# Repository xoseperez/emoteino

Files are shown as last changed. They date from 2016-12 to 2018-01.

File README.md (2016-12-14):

# Moteino Energy Monitor

A simple energy monitor shield for Moteino and the needed firmware to make it work with different configurations.

## Features

* LiPo battery connector with battery monitor at A7 (470k resistors for low power)
* Simple biased reading (low consumption voltage divider) with optional burden resistor
* 3.5mm jack input compatible with most CT out there
* Stackable up to 3 shields to read 3 different lines.
* Jumper pads to select input pin (A1, A2 or A3)

Check my **[Moteino Energy Monitor Shield][1]** post for further information about this project.

## Hardware

The hardware is shield for **Moteino** with a **battery monitor circuitry** and a **3.5mm plug** for commonly available current transformers (a.k.a. non-invasive current sensors). There is a footprint for an optional burden resistor (SMD0805) and a bias voltage divider using 2 470K resistors for low power consumption.

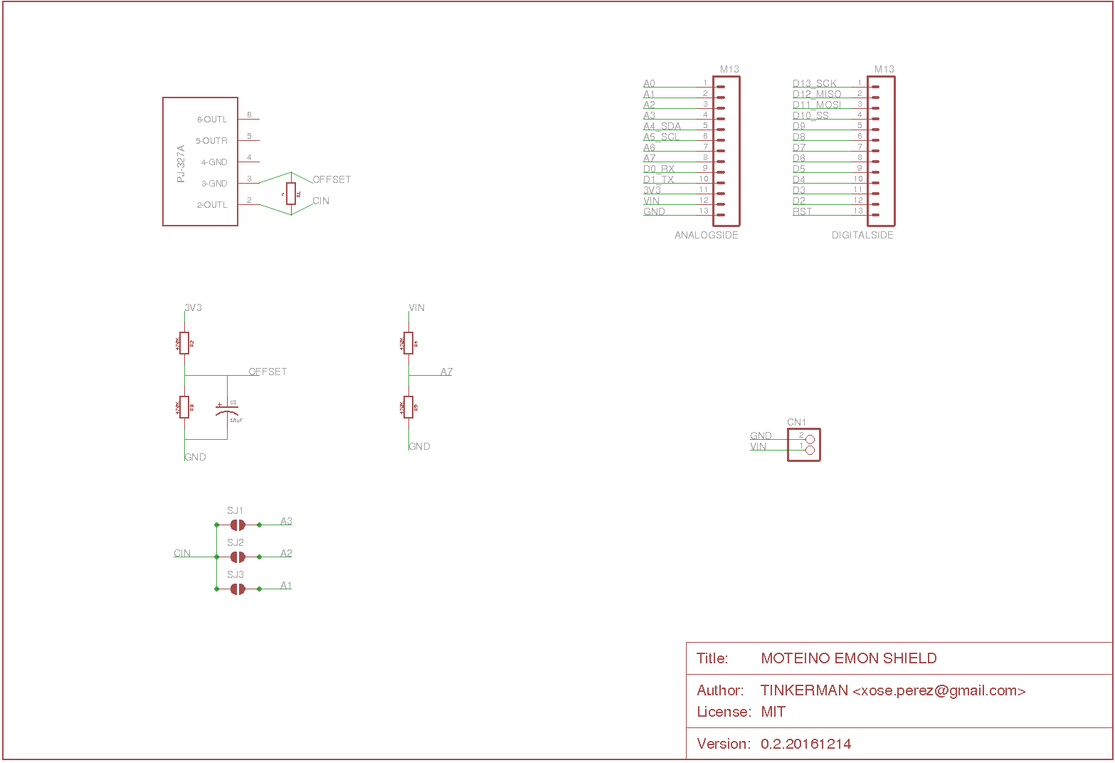
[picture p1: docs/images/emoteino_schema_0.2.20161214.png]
Energy Monitor Shield Schematic


The battery monitoring is based on a voltage divider with (again) two 470k resistors. The downstream resistor is tied to GND and the mid point to A7.

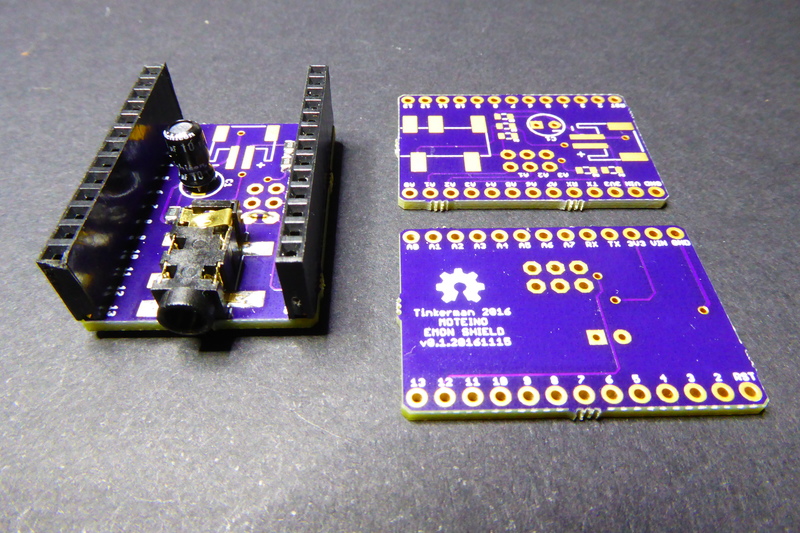
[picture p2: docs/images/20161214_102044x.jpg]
Energy Monitor Shield


## Firmware for Moteino + RFM69

### Dependencies

The code is very straight forward and there are comments where I thought it was important. It uses the following libraries:

* **[RFM69_ATC][3]** by Felix Rusu and Thomas Studwell
* **[Low-Power][4]** by RocketScream

These libraries will be automatically installed if you use [PlatformIO][2].

It also relies on my **RFM69Manager library** to wrap RFM69_ATC. This library manages radio setup and also message sending protocol. Messages from this node have the following format: ```<key>:<value>:<packetID>```. Packet ID is then used in the gateway to detect duplicates or missing packets from a node. If you don't want to send the packetID change the SEND_PACKET_ID value in RFM69Manager.h to 0.

### Configuration

Rename or copy the settings.h.sample file to settings.h and change its values to fit your needs. Check the descriptions for each value.

### Flashing

The project is ready to be build using **[PlatformIO][2]**.
Please refer to their web page for instructions on how to install the builder. Once installed connect the Moteino to your favourite FTDI-like programmer and:

```bash
> platformio run --target upload
```

[1]: http://tinkerman.cat/moteino-energy-monitor-shield/
[2]: http://www.platformio.org
[3]: https://github.com/LowPowerLab/RFM69
[4]: https://github.com/rocketscream/Low-Power/

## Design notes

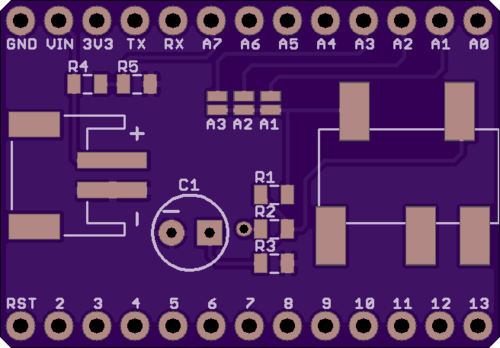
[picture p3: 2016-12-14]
docs/images/emoteino_board_0.2.20161214_top.png

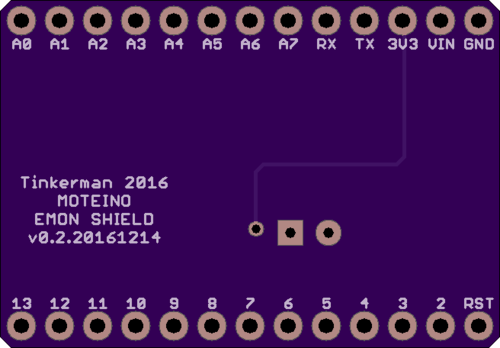
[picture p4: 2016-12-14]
docs/images/emoteino_board_0.2.20161214_bottom.png

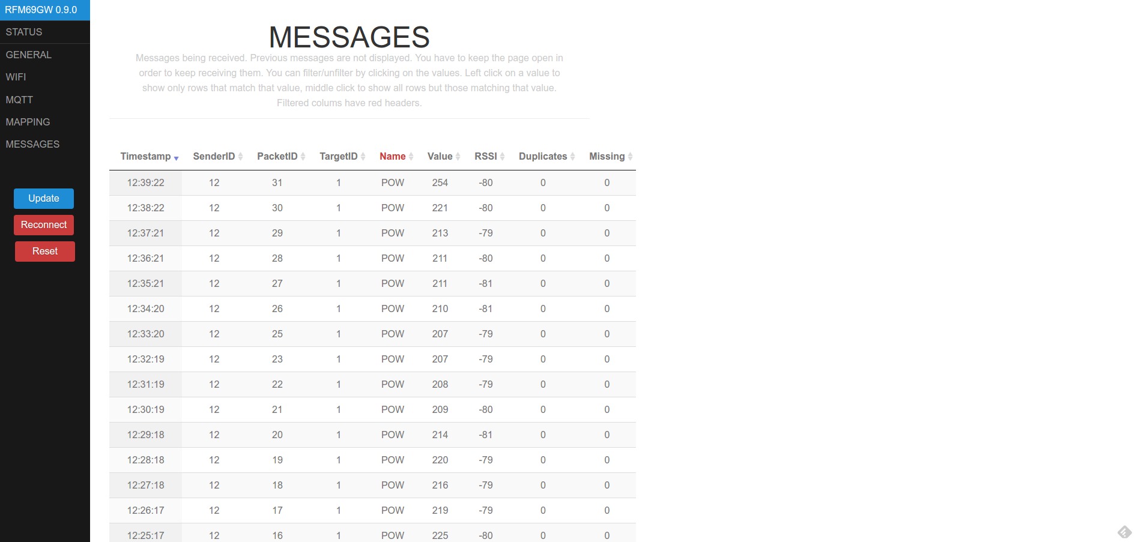
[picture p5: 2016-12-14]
docs/images/rfm69gw_screenshot.jpeg

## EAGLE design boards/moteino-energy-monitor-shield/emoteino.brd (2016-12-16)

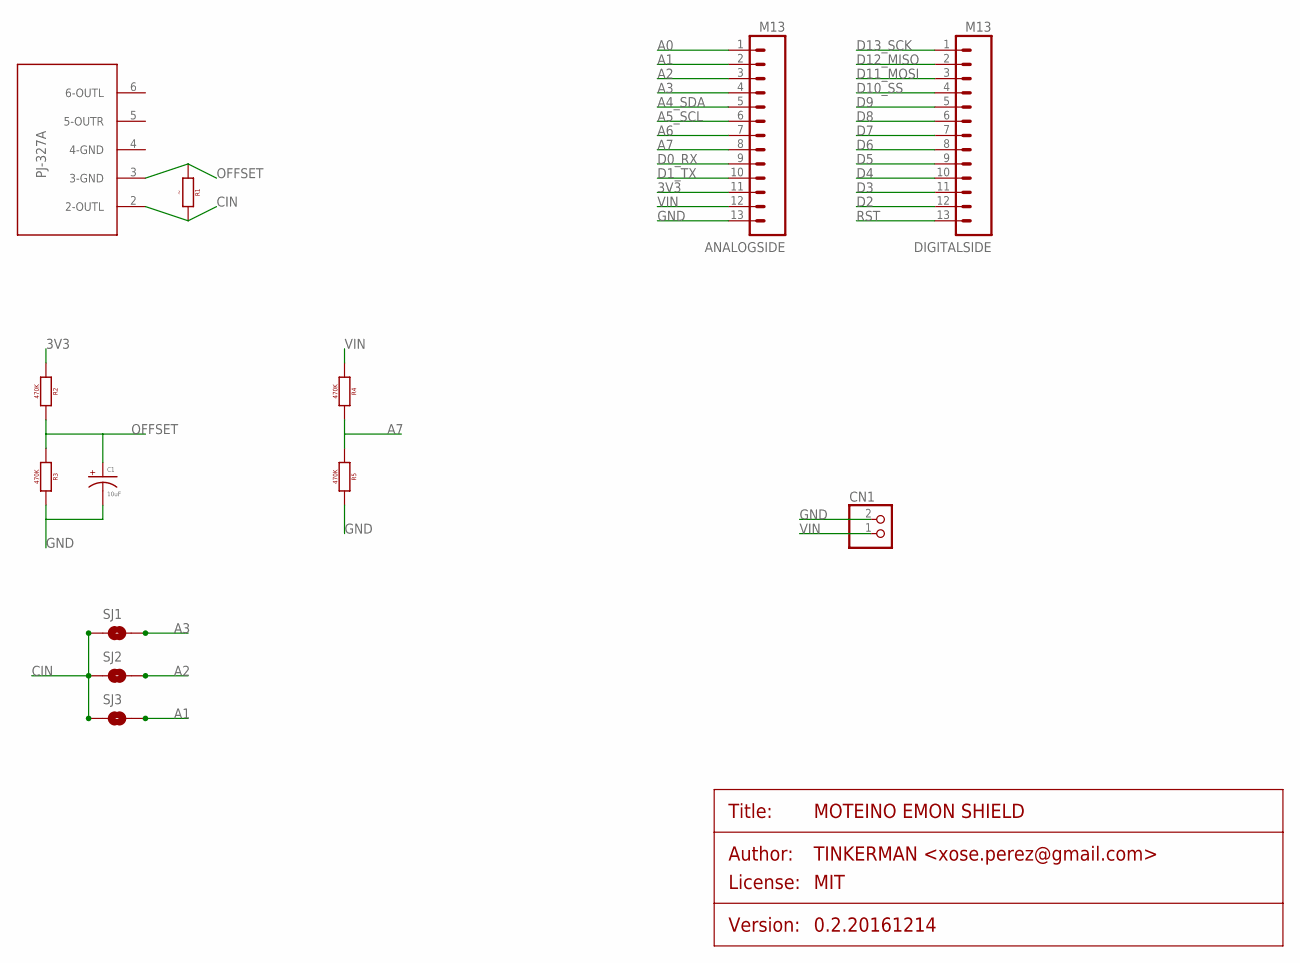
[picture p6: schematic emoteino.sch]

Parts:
ANALOGSIDE: M13; 1X13_NO_SILK
C1: 10uF; CPOL-RADIAL-10UF-25V
CN1: JST_2PIN-SMT-RA; JST-PH-2-SMT-RA
CURR1: PJ-327A
DIGITALSIDE: M13; 1X13_NO_SILK
R1: 0805
R2, R3, R4, R5: 470K; 0805
SJ1, SJ2, SJ3: SOLDERJUMPERNO; SJ_2S-NO

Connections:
3V3: ANALOGSIDE.11, R2.1
A0: ANALOGSIDE.1
A1: ANALOGSIDE.2, SJ3.2
A2: ANALOGSIDE.3, SJ2.2
A3: ANALOGSIDE.4, SJ1.2
A4_SDA: ANALOGSIDE.5
A5_SCL: ANALOGSIDE.6
A6: ANALOGSIDE.7
A7: ANALOGSIDE.8, R4.2, R5.1
CIN: CURR1.2 (2-OUTL), R1.2, SJ1.1, SJ2.1, SJ3.1
D0_RX: ANALOGSIDE.9
D1_TX: ANALOGSIDE.10
D2: DIGITALSIDE.12
D3: DIGITALSIDE.11
D4: DIGITALSIDE.10
D5: DIGITALSIDE.9
D6: DIGITALSIDE.8
D7: DIGITALSIDE.7
D8: DIGITALSIDE.6
D9: DIGITALSIDE.5
D10_SS: DIGITALSIDE.4
D11_MOSI: DIGITALSIDE.3
D12_MISO: DIGITALSIDE.2
D13_SCK: DIGITALSIDE.1
GND: ANALOGSIDE.13, C1.2 (-), CN1.2 (1), R3.2, R5.2
OFFSET: C1.1 (+), CURR1.3 (3-GND), R1.1, R2.2, R3.1
RST: DIGITALSIDE.13
VIN: ANALOGSIDE.12, CN1.1 (2), R4.1

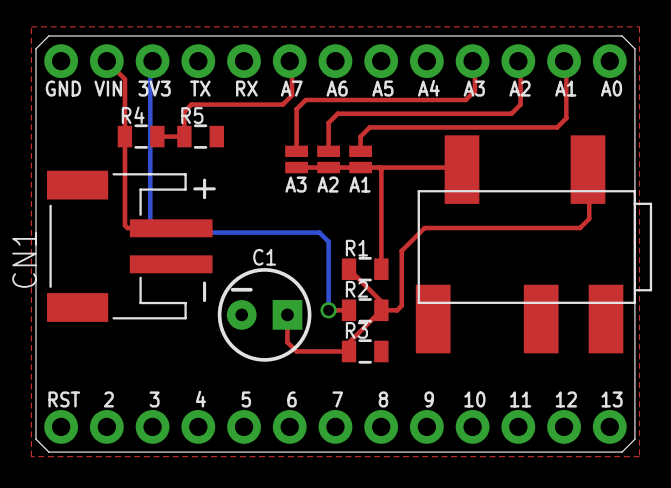
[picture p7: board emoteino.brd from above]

Board: 2 copper layers, 33.3 x 23.1 mm, 13 parts (0 on the bottom side), 9 nets.

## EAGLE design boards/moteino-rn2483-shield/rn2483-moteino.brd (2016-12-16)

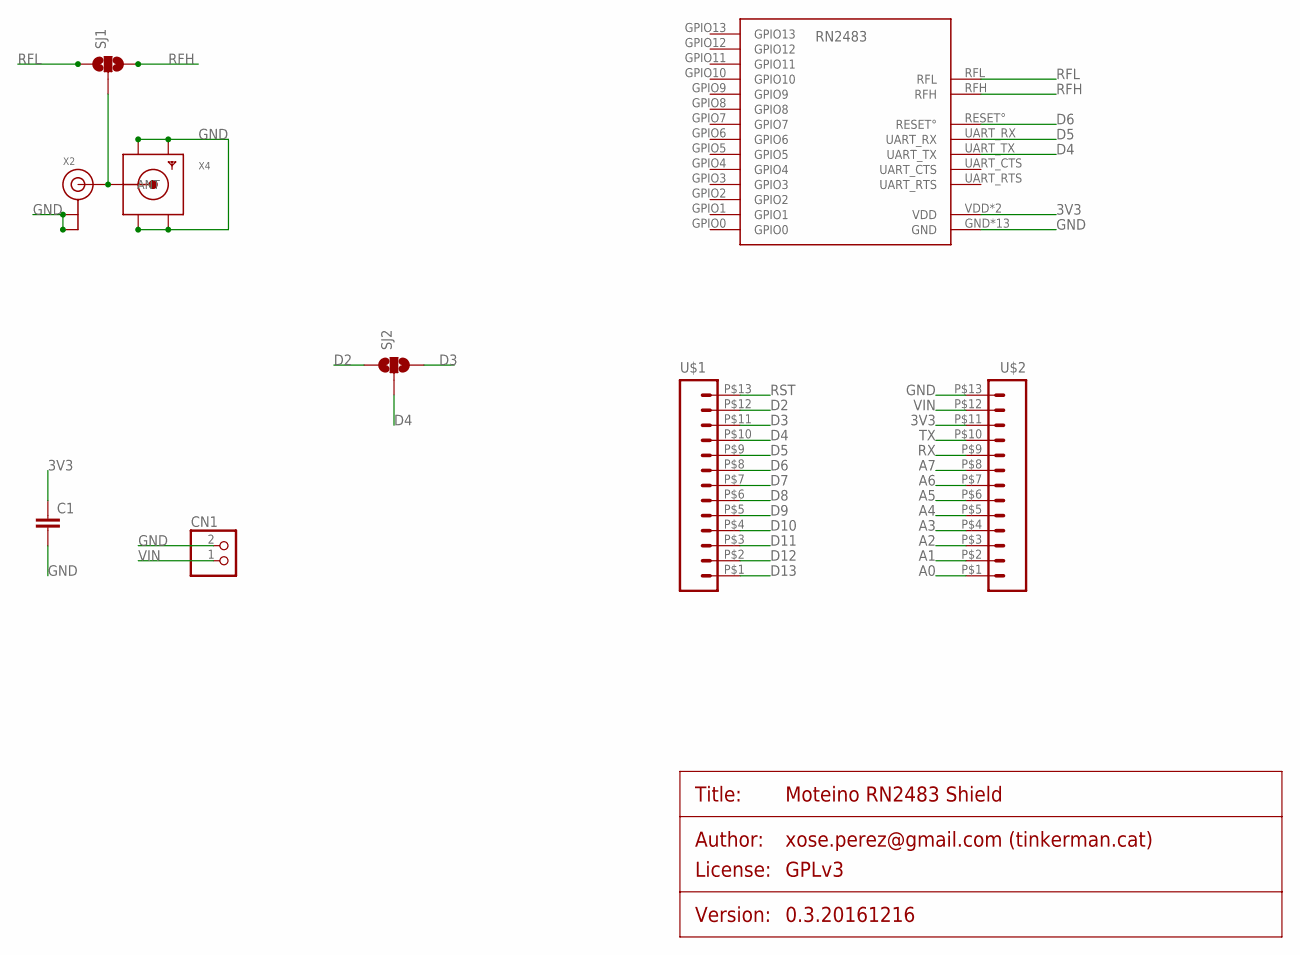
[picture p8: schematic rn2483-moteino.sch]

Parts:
C1: C-EU0805; 0805
CN1: JST_2PIN-SMT-RA; JST-PH-2-SMT-RA
RN2483: RN2483ALLPINS; RN2483
SJ1, SJ2: SOLDERJUMPER_2WAYS; SJ_3
U$1, U$2: M13M13_1X13_SMD; 1X13_SMD
X2: ANTENNA_U.FL; U.FL
X4: SMACONNECTOR_EDGE; SMA_EDGELAUNCH

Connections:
3V3: C1.1, RN2483.VDD, RN2483.VDD2 (VDD), U$2.P$11 (11)
A0: U$2.P$1 (1)
A1: U$2.P$2 (2)
A2: U$2.P$3 (3)
A3: U$2.P$4 (4)
A4: U$2.P$5 (5)
A5: U$2.P$6 (6)
A6: U$2.P$7 (7)
A7: U$2.P$8 (8)
D2: SJ2.1, U$1.P$12 (12)
D3: SJ2.3, U$1.P$11 (11)
D4: RN2483.UART_TX, SJ2.2, U$1.P$10 (10)
D5: RN2483.UART_RX, U$1.P$9 (9)
D6: RN2483.RESET°, U$1.P$8 (8)
D7: U$1.P$7 (7)
D8: U$1.P$6 (6)
D9: U$1.P$5 (5)
D10: U$1.P$4 (4)
D11: U$1.P$3 (3)
D12: U$1.P$2 (2)
D13: U$1.P$1 (1)
GND: C1.2, CN1.2 (1), RN2483.GND, RN2483.GND1 (GND), RN2483.GND2 (GND), RN2483.GND3 (GND), RN2483.GND4 (GND), RN2483.GND5 (GND), RN2483.GND6 (GND), RN2483.GND7 (GND), RN2483.GND8 (GND), RN2483.GND9 (GND), RN2483.GND10 (GND), RN2483.GND11 (GND), RN2483.GND12 (GND), U$2.P$13 (13), X2.1 (GND), X2.2 (GND), X4.GND@1 (GND4), X4.GND@2 (GND3), X4.GND@3 (GND2), X4.GND@4 (GND1)
unnamed: SJ1.2, X2.3 (SIGNAL), X4.P (ANT)
RFH: RN2483.RFH, SJ1.3
RFL: RN2483.RFL, SJ1.1
RST: U$1.P$13 (13)
RX: U$2.P$9 (9)
TX: U$2.P$10 (10)
VIN: CN1.1 (2), U$2.P$12 (12)

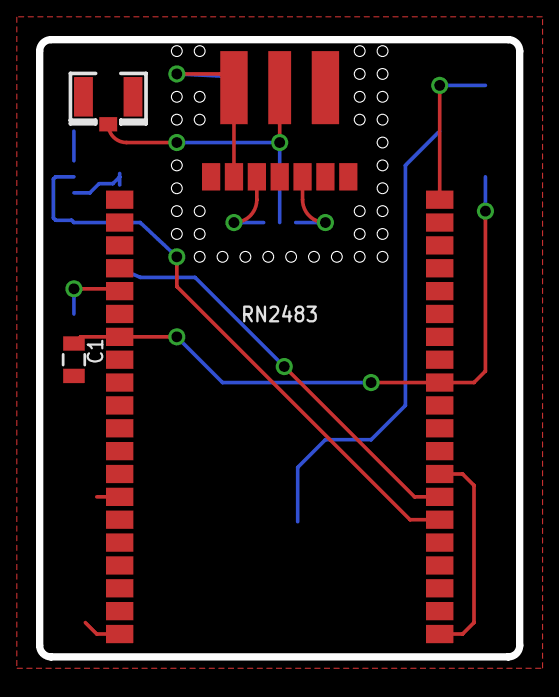
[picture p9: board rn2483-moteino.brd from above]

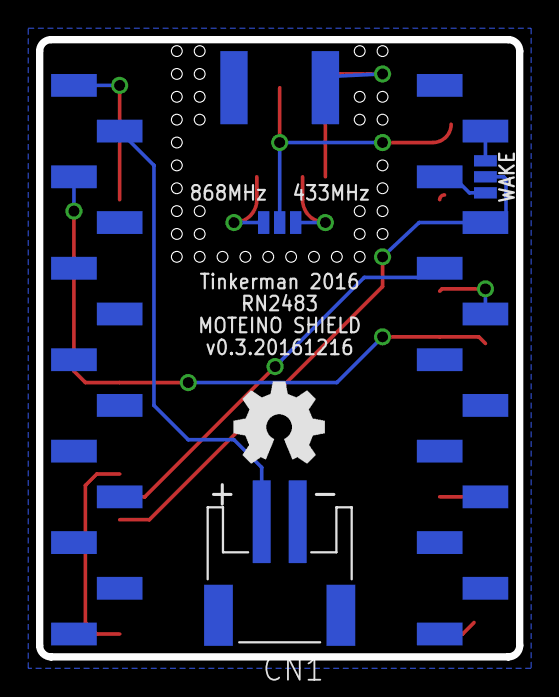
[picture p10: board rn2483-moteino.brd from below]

Board: 2 copper layers, 26.7 x 34.3 mm, 9 parts (5 on the bottom side), 11 nets.

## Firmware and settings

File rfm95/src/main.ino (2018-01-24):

/*

RFM95 TTN EU NODE

Copyright (C) 2016-2018
Xose Pérez <xose dot perez at gmail dot com>
for The Things Network Catalunya Wiki (http://thethingsnetwork.cat)
Based on LMIC library example

This sketch sends an incrementing number every minute

This sketch requires LMIC library by Matthijs Kooijman
https://github.com/matthijskooijman/arduino-lmic

// -----------------------------------------------------------------------------
// Moteino LoRa
// https://lowpowerlab.com/shop/product/99
// -----------------------------------------------------------------------------

You will have to wire the folowing extra pins from the RFM95 module to Moteino ports:

  RFM95     Moteino
  --------  --------
  RESET     D4
  DIO1      D5
  DIO2      D6

RFM95 module pinout (top view, with the chip facing you) and the corresponding
Moteino PIN connected (wire the ones marked with an asterisk *)
        |-------------|
    GND | GND    DIO2 | D6*
    D12 | MISO   DIO1 | D5*
    D11 | MOSI   DIO0 | D2
    D13 | SCK     3V3 | 3V3
    D10 | NSS    DIO4 |
    *D4 | RESET  DIO3 |
        | DIO5    GND | GND
    GND | GND     ANT |
        |-------------|

// -----------------------------------------------------------------------------
// CH2i Wemos LoRa Shield
// https://github.com/hallard/WeMos-Lora
// -----------------------------------------------------------------------------

Default connections apply.

// -----------------------------------------------------------------------------
// Heltec WIFI LoRa 32
// https://robotzero.one/heltec-wifi-lora-32/
// -----------------------------------------------------------------------------

GPIO5  -- SX1278's SCK
GPIO19 -- SX1278's MISO
GPIO27 -- SX1278's MOSI
GPIO18 -- SX1278's CS
GPIO14 -- SX1278's RESET
GPIO26 -- SX1278's IRQ(Interrupt Request)

RFM95 module pinout (top view, with the chip facing you) and the corresponding
ESP32 PIN connected:

        |-------------|
    GND | GND    DIO2 | 32
     19 | MISO   DIO1 | 33
     27 | MOSI   DIO0 | 26
      5 | SCK     3V3 | 3V
     18 | NSS    DIO4 |
     14 | RESET  DIO3 |
        | DIO5    GND | GND
    GND | GND     ANT |
        |-------------|

// -----------------------------------------------------------------------------

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
*/

#include <Arduino.h>
#include <lmic.h>
#include <hal/hal.h>
#include <SPI.h>

#ifndef CFG_eu868
    #error "This script is meant to connect to TTN EU network at 868MHz"
#endif

// -----------------------------------------------------------------------------
// Configuration
// -----------------------------------------------------------------------------

#define SERIAL_BAUD         115200      // Serial debug baud rate
#define TX_INTERVAL         60          // Send message every these many seconds

// Copy and rename credentials.sample.h to credentials.h
// and configure it with your node settings
#include "credentials.h"

// Define device type
// Only one of these must be defined at the same time
//#define MOTEINO_LORA
//#define CH2I_WEMOS_LORA_SHIELD
//#define HELTEC_WIFI_LORA_32

// -----------------------------------------------------------------------------
// GPIO mapping
// -----------------------------------------------------------------------------

#ifdef MOTEINO_LORA
    #define NSS_GPIO        10
    #define RESET_GPIO      4
    #define DIO0_GPIO       2
    #define DIO1_GPIO       5
    #define DIO2_GPIO       6
#endif

#ifdef CH2I_WEMOS_LORA_SHIELD
    #define NSS_GPIO        16
    #define RESET_GPIO      LMIC_UNUSED_PIN
    #define DIO0_GPIO       15
    #define DIO1_GPIO       15
    #define DIO2_GPIO       15
#endif

#ifdef HELTEC_WIFI_LORA_32
    #define SCK_GPIO        5
    #define MISO_GPIO       19
    #define MOSI_GPIO       27
    #define NSS_GPIO        18
    #define RESET_GPIO      14
    #define DIO0_GPIO       26
    #define DIO1_GPIO       33
    #define DIO2_GPIO       32
#endif

#ifndef NSS_GPIO
    #error "GPIO are not mapped!!"
#endif

// -----------------------------------------------------------------------------
// Globals
// -----------------------------------------------------------------------------

// LMIC GPIO configuration
const lmic_pinmap lmic_pins = {
    .nss = NSS_GPIO,
    .rxtx = LMIC_UNUSED_PIN,
    .rst = RESET_GPIO,
    .dio = {DIO0_GPIO, DIO1_GPIO, DIO2_GPIO},
};

#if !defined(USE_ABP) && !defined(USE_OTAA)
    #error "Define either USE_ABP or USE_OTAA in credentials.h"
#endif

#ifdef USE_ABP
// These callbacks are only used in over-the-air activation, so they are
// left empty here (we cannot leave them out completely unless
// DISABLE_JOIN is set in config.h, otherwise the linker will complain).
void os_getArtEui (u1_t* buf) { }
void os_getDevEui (u1_t* buf) { }
void os_getDevKey (u1_t* buf) { }
#endif

#ifdef USE_OTAA
void os_getArtEui (u1_t* buf) { memcpy_P(buf, APPEUI, 8); }
void os_getDevEui (u1_t* buf) { memcpy_P(buf, DEVEUI, 8); }
void os_getDevKey (u1_t* buf) { memcpy_P(buf, APPKEY, 16); }
#endif

// Job
static osjob_t sendjob;

// Value
unsigned long autoincrement = 0;

// -----------------------------------------------------------------------------
// LMIC
// -----------------------------------------------------------------------------

void ttnSend(osjob_t* j){

    // Check if there is not a current TX/RX job running
    if (LMIC.opmode & OP_TXRXPEND) {
        Serial.println(F("[RFM95] Pending message"));
        return;
    }

    // Prepare buffer
    unsigned char data[4];
    data[0] = (autoincrement >> 24) & 0xFF;
    data[1] = (autoincrement >> 16) & 0xFF;
    data[2] = (autoincrement >>  8) & 0xFF;
    data[3] = (autoincrement >>  0) & 0xFF;

    // Prepare upstream data transmission at the next possible time.
    // Parameters are port, data, length, confirmed
    LMIC_setTxData2(1, data, 4, 0);

    Serial.println(F("[RFM95] Packet queued"));

    // Next TX is scheduled after TX_COMPLETE event.
    autoincrement++;

}

// LMIC library will call this method when an event is fired
void onEvent(ev_t ev) {

    Serial.print(os_getTime());
    Serial.print(": ");

    switch(ev) {
        case EV_SCAN_TIMEOUT:
            Serial.println(F("[RFM95] EV_SCAN_TIMEOUT"));
            break;
        case EV_BEACON_FOUND:
            Serial.println(F("[RFM95] EV_BEACON_FOUND"));
            break;
        case EV_BEACON_MISSED:
            Serial.println(F("[RFM95] EV_BEACON_MISSED"));
            break;
        case EV_BEACON_TRACKED:
            Serial.println(F("[RFM95] EV_BEACON_TRACKED"));
            break;
        case EV_JOINING:
            Serial.println(F("[RFM95] EV_JOINING"));
            break;
        case EV_JOINED:
            Serial.println(F("[RFM95] EV_JOINED"));
            break;
        case EV_RFU1:
            Serial.println(F("[RFM95] EV_RFU1"));
            break;
        case EV_JOIN_FAILED:
            Serial.println(F("[RFM95] EV_JOIN_FAILED"));
            break;
        case EV_REJOIN_FAILED:
            Serial.println(F("[RFM95] EV_REJOIN_FAILED"));
            break;
        case EV_TXCOMPLETE:

            Serial.println(F("[RFM95] EV_TXCOMPLETE (includes waiting for RX windows)"));

            if (LMIC.txrxFlags & TXRX_ACK) {
                Serial.println(F("[RFM95] ACK received"));
            }

            if (LMIC.dataLen) {
                Serial.print(F("[RFM95] Received "));
                Serial.print(LMIC.dataLen);
                Serial.println(F(" bytes of payload"));
            }

            // Schedule next transmission
            os_setTimedCallback(&sendjob, os_getTime() + sec2osticks(TX_INTERVAL), ttnSend);
            break;

        case EV_LOST_TSYNC:
            Serial.println(F("[RFM95] EV_LOST_TSYNC"));
            break;
        case EV_RESET:
            Serial.println(F("[RFM95] EV_RESET"));
            break;
        case EV_RXCOMPLETE:
            // data received in ping slot
            Serial.println(F("[RFM95] EV_RXCOMPLETE"));
            break;
        case EV_LINK_DEAD:
            Serial.println(F("[RFM95] EV_LINK_DEAD"));
            break;
        case EV_LINK_ALIVE:
            Serial.println(F("[RFM95] EV_LINK_ALIVE"));
            break;
        default:
            Serial.println(F("[RFM95] Unknown event"));
            break;

    }

}

void ttnSetup() {

    // LMIC init
    os_init();

    // Reset the MAC state. Session and pending data transfers will be discarded.
    LMIC_reset();

    #ifdef USE_ABP

        // Set static session parameters. Instead of dynamically establishing a session
        // by joining the network, precomputed session parameters are be provided.
        uint8_t appskey[sizeof(APPSKEY)];
        uint8_t nwkskey[sizeof(NWKSKEY)];
        memcpy_P(appskey, APPSKEY, sizeof(APPSKEY));
        memcpy_P(nwkskey, NWKSKEY, sizeof(NWKSKEY));
        LMIC_setSession(0x1, DEVADDR, nwkskey, appskey);

        // Set up the channels used by the Things Network, which corresponds
        // to the defaults of most gateways. Without this, only three base
        // channels from the LoRaWAN specification are used, which certainly
        // works, so it is good for debugging, but can overload those
        // frequencies, so be sure to configure the full frequency range of
        // your network here (unless your network autoconfigures them).
        // Setting up channels should happen after LMIC_setSession, as that
        // configures the minimal channel set.
        LMIC_setupChannel(0, 868100000, DR_RANGE_MAP(DR_SF12, DR_SF7),  BAND_CENTI);      // g-band
        LMIC_setupChannel(1, 868300000, DR_RANGE_MAP(DR_SF12, DR_SF7B), BAND_CENTI);      // g-band
        LMIC_setupChannel(2, 868500000, DR_RANGE_MAP(DR_SF12, DR_SF7),  BAND_CENTI);      // g-band
        LMIC_setupChannel(3, 867100000, DR_RANGE_MAP(DR_SF12, DR_SF7),  BAND_CENTI);      // g-band
        LMIC_setupChannel(4, 867300000, DR_RANGE_MAP(DR_SF12, DR_SF7),  BAND_CENTI);      // g-band
        LMIC_setupChannel(5, 867500000, DR_RANGE_MAP(DR_SF12, DR_SF7),  BAND_CENTI);      // g-band
        LMIC_setupChannel(6, 867700000, DR_RANGE_MAP(DR_SF12, DR_SF7),  BAND_CENTI);      // g-band
        LMIC_setupChannel(7, 867900000, DR_RANGE_MAP(DR_SF12, DR_SF7),  BAND_CENTI);      // g-band
        LMIC_setupChannel(8, 868800000, DR_RANGE_MAP(DR_FSK,  DR_FSK),  BAND_MILLI);      // g2-band

        // TTN defines an additional channel at 869.525Mhz using SF9 for class B
        // devices' ping slots. LMIC does not have an easy way to define set this
        // frequency and support for class B is spotty and untested, so this
        // frequency is not configured here.

        // Disable link check validation
        LMIC_setLinkCheckMode(0);

        // TTN uses SF9 for its RX2 window.
        LMIC.dn2Dr = DR_SF9;

        // Set data rate and transmit power for uplink (note: txpow seems to be ignored by the library)
        LMIC_setDrTxpow(DR_SF7, 14);

    #endif // USE_ABP

    // Start job
    ttnSend(&sendjob);

}

// -----------------------------------------------------------------------------
// Main methods
// -----------------------------------------------------------------------------

void setup() {

    // Init serial port for debugging
    Serial.begin(115200);
    Serial.println("[MAIN] Startup");

    // SPI interface
    #ifdef ESP32
        SPI.begin(SCK_GPIO, MISO_GPIO, MOSI_GPIO, NSS_GPIO);
    #endif

    // Init LMIC library to work with TTN EU
    ttnSetup();

}

void loop() {

    // Keeps track of the scheduled jobs
    os_runloop_once();

}

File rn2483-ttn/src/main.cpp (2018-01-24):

/*

MOTEINO LORAWAN NODE

Copyright (C) 2016 by Xose Pérez <xose dot perez at gmail dot com>

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
*/

#include <Arduino.h>
#include <SoftwareSerial.h>
#include <TheThingsNetwork.h>
#include <LowPower.h>
#include "settings.h"

// -----------------------------------------------------------------------------
// Globals
// -----------------------------------------------------------------------------

// Hold the last time we wake up, to calculate how much we have to sleep next time
unsigned long wakeTime = millis();

// Hold current sum
double current;

// Counts the one minute parcials, values from 0 to 5 (6 parcials)
byte count1 = 0;

// Counts de 5 minutes power consumptions, values from 0 to 4 (5 values)
byte count2 = 0;

// Holds de 5 minutes power consumptions, values from 0 to 4 (5 values)
unsigned int power[SENDING_COUNTS];

SoftwareSerial loraSerial(SOFTSERIAL_RX_PIN, SOFTSERIAL_TX_PIN);
TheThingsNetwork ttn(loraSerial, Serial, TTN_FREQPLAN);

// -----------------------------------------------------------------------------
// Utils
// -----------------------------------------------------------------------------

void blink(byte times, byte mseconds) {
    pinMode(LED_PIN, OUTPUT);
    for (byte i=0; i<times; i++) {
        if (i>0) delay(mseconds);
        digitalWrite(LED_PIN, HIGH);
        delay(mseconds);
        digitalWrite(LED_PIN, LOW);
    }
    pinMode(LED_PIN, INPUT);
}

// -----------------------------------------------------------------------------
// Readings
// -----------------------------------------------------------------------------

// Based on EmonLib calcIrms method
double getCurrent(unsigned long samples) {

    static double offset = (ADC_COUNTS >> 1);
    unsigned long sum = 0;

    for (unsigned int n = 0; n < samples; n++) {

        // Get the reading
        unsigned long reading = analogRead(CURRENT_PIN);

        // Digital low pass
        offset = ( offset + ( reading - offset ) / 1024 );
        unsigned long filtered = reading - offset;

        // Root-mean-square method current
        sum += ( filtered * filtered );

    }

    double current = CURRENT_RATIO * sqrt(sum / samples) * ADC_REFERENCE / ADC_COUNTS;
    #ifdef DEBUG
        Serial.print("[MAIN] Current (A): ");
        Serial.println(current);
    #endif
    return current;

}

unsigned int getBattery() {
    unsigned int voltage = BATTERY_RATIO * analogRead(BATTERY_PIN);
    #ifdef DEBUG
        Serial.print("[MAIN] Battery: ");
        Serial.println(voltage);
    #endif
    return voltage;
}

// -----------------------------------------------------------------------------
// Sleeping
// -----------------------------------------------------------------------------

void awake() {
    // Nothing to do
}

bool sleepRadio() {
    #ifdef DEBUG
        Serial.println("[MAIN] Sleeping the radio");
    #endif
    bool response = true;
    ttn.sleep(SLEEP_INTERVAL - millis() + wakeTime);
    if (loraSerial.available()) loraSerial.read();
    return response;
}

void sleepController() {
    #ifdef DEBUG
        Serial.println("[MAIN] Sleeping the controller");
        Serial.println();
        delay(10);
    #endif
    attachInterrupt(1, awake, CHANGE);
    LowPower.powerDown(SLEEP_FOREVER, ADC_OFF, BOD_OFF);
    wakeTime = millis();
    detachInterrupt(1);
    if (loraSerial.available()) loraSerial.read();
    #ifdef DEBUG
        Serial.println("[MAIN] Awake!");
    #endif
}

// -----------------------------------------------------------------------------
// Actions
// -----------------------------------------------------------------------------

// Reads the sensor value and adds it to the accumulator
void doRead() {
    current = current + getCurrent(CURRENT_SAMPLES);
}

// Stores the current average into the minutes array
void doStore() {
    power[count2-1] = (current * MAINS_VOLTAGE) / READING_COUNTS;
    #ifdef DEBUG
        char buffer[50];
        sprintf(buffer, "[MAIN] Storing power in slot #%d: %dW\n", count2, power[count2-1]);
        Serial.print(buffer);
    #endif
    current = 0;
}

// Sends the 5 minute averages
void doSend() {

    byte size = SENDING_COUNTS * 2 + 2;
    byte payload[size];

    for (int i=0; i<SENDING_COUNTS; i++) {
        payload[i*2] = (power[i] >> 8) & 0xFF;
        payload[i*2+1] = power[i] & 0xFF;
    }

    unsigned int voltage = getBattery();
    payload[SENDING_COUNTS * 2] = (voltage >> 8) & 0xFF;
    payload[SENDING_COUNTS * 2 + 1] = voltage & 0xFF;

    #ifdef DEBUG
        Serial.print("[MAIN] Sending: ");
        char buffer[6];
        for (byte i=0; i<size; i++) {
            sprintf(buffer, "0x%02X ", payload[i]);
            Serial.print(buffer);
        }
        Serial.println();
    #endif
    ttn.sendBytes(payload, SENDING_COUNTS * 2 + 2, 1, false);

}

// -----------------------------------------------------------------------------
// RN2483
// -----------------------------------------------------------------------------

void loraReset() {
    pinMode(RN2483_RESET_PIN, OUTPUT);
    digitalWrite(RN2483_RESET_PIN, HIGH);
    delay(50);
    digitalWrite(RN2483_RESET_PIN, LOW);
    delay(50);
    digitalWrite(RN2483_RESET_PIN, HIGH);
    delay(50);
    while (!loraSerial.available()) delay(100);
    while (loraSerial.available()) loraSerial.read();
}

// -----------------------------------------------------------------------------
// Main
// -----------------------------------------------------------------------------

void setup() {

    #ifdef DEBUG
        Serial.begin(SERIAL_BAUD);
        Serial.println("[MAIN] LoRaWAN Current Sensor v0.1-ttn");
    #endif

    //pinMode(CURRENT_PIN, INPUT);
    //pinMode(BATTERY_PIN, INPUT);

    // Warmup the current monitoring
    getCurrent(CURRENT_SAMPLES * 3);

    // Configure radio
    loraSerial.begin(SOFTSERIAL_BAUD);
    loraSerial.flush();
    loraReset();

    #if TTN_ABP
        ttn.personalize(TTN_DEVADDR, TTN_NWKSKEY, TTN_APPSKEY);
        ttn.showStatus();
    #else
        ttn.showStatus();
        ttn.join(TTN_APPEUI, TTN_APPKEY);
    #endif

    // Set initial wake up time
    wakeTime = millis();

}

void loop() {

    // Update counters
    if (++count1 == READING_COUNTS) ++count2;

    // We are only sending if both counters have overflown
    // so to save power we shutoff the radio now if no need to send
    if (count2 < SENDING_COUNTS) sleepRadio();

    // Visual notification
    blink(1, 5);

    // Always perform a new reading
    doRead();

    // We are storing it if count1 has overflown
    if (count1 == READING_COUNTS) doStore();

    // We are only sending if both counters have overflow
    if (count2 == SENDING_COUNTS) {
        blink(3, 5);
        doSend();
        sleepRadio();
    }

    // Overflow counters
    count1 %= READING_COUNTS;
    count2 %= SENDING_COUNTS;

    // Sleep the controller, the radio will wake it up
    sleepController();

}

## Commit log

2016-12-16 Clean up Moteino Energy Monitor Shield board
    [emoteino.brd]
2016-12-16 Moteino RN2483 Shield
    [emoteino.brd, emoteino.sch, rn2483-moteino.brd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]
2018-01-24 Changes in the schematic
    [emoteino.sch]
2018-01-24 RFM95 examples for Moteino, Wemos Lora Shield and ESP32
2021-05-07 Disable ATC, sending MAX power consumption

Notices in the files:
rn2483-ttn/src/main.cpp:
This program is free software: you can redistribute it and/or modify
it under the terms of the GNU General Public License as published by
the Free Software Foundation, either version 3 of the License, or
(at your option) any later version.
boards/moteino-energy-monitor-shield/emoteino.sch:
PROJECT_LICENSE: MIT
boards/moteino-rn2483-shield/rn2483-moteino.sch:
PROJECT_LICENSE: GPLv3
